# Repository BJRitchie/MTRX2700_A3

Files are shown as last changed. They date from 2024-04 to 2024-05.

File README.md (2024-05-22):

# MTRX2700 Major Project - The a-MAZE-ing Race
## Project Details:
The a-MAZE-ing Race is a competitive maze game with the objective of reaching all the checkpoints on the maze board as fast as possible. 

## Group Members
- Sebastian O'Connell (520443826)
- Ben Ritchie (520479733)
- Luca Agius (520510715)
- Will Ridley-Smith (520466021)

## Roles & Responsibilities
### Will Ridley-Smith
- Joystick Module
- Servo/Joystick integration 
- 3D printing and assembly

### Luca Agius
- LDR, GUI, and Serial Modules
- Documentation lead

### Sebastian O'Connell
- LDR, GUI, and Serial Modules
- Presentation slides
- Minutes documentation

### Ben Ritchie
- CAD design of gimbaling system 
- Servo Module
- Servo/Joystick integration
- Minutes documentation

## Module Breakdown

## Serial Communication Module
### Summary
Serial communication facilitates the transmission of data between modules to ensure they work together correctly.
### Usage
The LDR and GUI modules rely on packets sent over serial to communicate and ultimately carry out a usuable function. Using an interrupt based approach, the modules can function simultaneously, allowing for the game to function smoothly. 
### Valid input
Sorted data can be inputted into the SerialOutputString function and sent over USART1 to the PC to utilise serial communication.
### Functions and modularity
#### Transmission
SerialOutputString: This function is the most essential function in the serial communicaion process. It is used to output a specific string over the serial port using a pre-determined baud rate. The baud rate must match that at the receiving end.
SerialInitialise: Initialises the serial port and specified baud rate
### Testing
Messages can manually be sent over the serial port using the SerialOutputBuffer. To confirm that these messages are being sent/received, a terminal such as the PuTTY terminal can be used. The PuTTY terminal should be given the correct COM line to read from, and the appropriate baud rate. When a message is written into the SerialOutputBuffer and the code is run, the PuTTY terminal should receive the string. 

## Joystick Module
### Summary
Potentiometers track the rotation of a joystick on 2 axis'. A voltage divider is used to track the values of the position of the potentiometer. This voltage signal is passed into an analog to digital converter to get the values. A range is found for the joystick and then the values are mapped so that each coordinate is a value from 0-1000.

### Usage
To use the module, simply initialise the ADC with InitialiseADC() and use get_joystick_values() to get the current coordinates of the joystick. The values of the coordinates range from 0-1000. WHen the joystick is connected, x is 0 when all the way to the left and 1000 when all the way to the right. Y is 1000 when all the way forwards and 0 when all the way back. In this assignment, a loop continuously calls get_joystick_values() so that we are always checking the position of the joystick.

### Valid input
A pointer to a valid struct joystick_coordinates should be passed into the get_joystick_values() function.
Variable voltage should be connected to PA1 and PA5 and should have a max value of 3V.

### Functions and modularity
InitialiseADC() runs all required setup for the ADC module.
get_joystick_values() simply returns the current coordinates of the joystick.
All functionality is encapsulated within these functions.

### Testing
Connect inputs for the joystick module and initialise Serial. Use Serial Output to print the values from ADC to the terminal on a computer. Check that the y value varies when moving the joystick forward and backwards, and the x value varies when moving side to side.

Print the mapped x and y values to the screen and check that at the furthest forward position, y is 1000, and the furthest backwards, y is 0. Also check that all the way to the right, x is 1000 and all the way to the left, x is 0.

## Servo Module
### Summary
The servo module is designed for simple integration, where the user can input a value from 0 to 1, where 0 is the minimum allowable angular displacement and 1 is the maximum allowable position for the servo. Each servo is described inside a struct that contains the responsible hardware timer, channel and the maximum and minimum permissible PWM values. It also contains parameters that relate to velocity control functions. 

The servo module also contains a PID controller for velocity, which uses the PWM signal period to adjust the servo velocity and the on-board gyroscope to check the actual rotational velocity. The target (requested) velocity can be adjusted at any time using the setTargetVelocity function. This value is check at a regular interval by the PID controller, which will adjust the PWM period until it reaches an acceptable error range. 

### Usage
The servo module will be linked to the joystick module. The joystick module will request a value from 0 to 1 in the x and y axes and the servos will go to this position. 

One could also configure the joystick to control the rotational velocity of the board by adjusting the target velocity values, and the velocity control module will adjust the PWM period as required. 

### Valid input
A positional value from 0 to 1 can be requested. 

### Functions and modularity
#### Positional Control 
servoGoToFractionalPosition: will go to the requested fraction of its positional range. 
setServoPWM: sets the requested PWM value. 

#### Velocity Control 
initPIDController: initialises the PID controller for the servo 
setTargetVelocity: sets the target rotational velocity of the servo.
servoGoToFractionalVelocity: make the servo go at a fraction of the allowable range. 

### Testing

## LDR/Gameplay Module 
### Summary
There are 4 LDRs used in the game that are setup to work with the ADC ports. There is one LDR which is used as the starting point of the game, and when this LDR is blocked for three seconds, the game begins. Hardware timers are used to time the game, one timer counts every seconds and another timer counts every 100th of a second. Once the game is being played, the fast-acting timer checks to see whether any of the other three LDRs have been blocked. If all three have been blocked once, then the game is finished.

### Usage
The LDR module features the resistive sensors required for this assignment and it they are used inside the maze. This module is essentially the module where the game is run and the game settings are configured.
The LDRs are powered off of the STM board but they are wired with resistors to ground. A wire connects the LDR output to a comparator which is compared to a tuned potentiometer. The inputs to the ADC ports are taken from the four outputs of the LM324 comparator

### Valid input
Changing light levels incident on the LDR are valid for using this module. The best way to use this is to have a very bright light in contrast with a very dark light.

### Functions and modularity
The ADC ports are used to check the readings from the LDRs and then interpreted using a scale value. This module only has a 2-value scale as it only cares if the LDR is on or off. The scale values are then stored in the ADC port which can be used in the main function. 
The timer code is taken from the previous assignment but has a struct to initialise the timers and some other functions to configure the timers
The gameplay code is a separate file and contains functions relating to how the game is played. This includes functions that call the ADC, interrupt, and timer initialisation functions from the other modular files. This part of the code has a struct called GameData which contains the game setting information and configuration, this can be changed to change the game settings slightly. It also contains a function called FlashEndLights which is called once all the LDRs/checkpoints have been passed and this flashes until the game is reset.

### Testing
To test this module, the STM LEDs have been configured to visually debug the system. The LDRs are set to trigger 1 of 2 LEDs, an LED for off and an LED for on. If the LED changes when you block the LDR then the potentiometer, LDR, and code has been tuned effectively. 
The LEDs are then also used to test whether the gameplay is working smoothly. During phase 1, the LEDs are set to only respond to the starting point LDR and will change when that LDR is blocked. Between game phase 1 and 2, three LEDs flash to inform the user that the game is about to begin. Then in the game playing phase, 2 LEDs are then set to respond to 1 LDR as describe earlier. Since there are 3 LDRs used in this phase, then 6 LEDs are used. When each LDR has been blocked once, you know the game is finished because the cool end light patterns will flash. To reset the game, hit the blue button and you will see all the LEDs flash and then the game will reset to phase 1. 

## GUI Module 
maze
### Summary
The GUI is generated using python code to display a timer when the game starts, and employs a leaderboard to track the quickest times. 
### Usage
The GUI module aims to replicate the quality features of a real arcade game. This module is essential in transforming the design from a casual toy into a competitive game with various interactive and engaging features. Implementing a timer with an associated leaderboard, music and checkpoint indicators changes the games usage to being a quantifiable race.  
### Valid input
The GUI code must be run on a valid python coding platform that has the capability to generate a GUI pop-up application (such as VSCode).
### Functions and modularity
The timer will be idle until it receives a specific packet over serial indicating the game has started - this occurs when the maze marble sits in the starting position for three seconds. The timer will continue to run until all of the checkpoints are reached. Once all the checkpoints are reached by the marble, a packet will be sent over serial indicating the game has ended. The timer will stop, reset to zero and sit idle until the game is started again. Additionally, once the game ends, there is a pop-up request for a username input. After inputting a username, the time taken to finish the game and username will be displayed on the leaderboard in the appropriate position, with the fastest time at the top of the leaderboard.
#### Serial
The python module "pyserial" is installed onto the device and imported into the code to access serial. The serial packet is sent from the STM32F3Discovery board and interpretted by the python code.
#### tkinter
The python module "tkinter" is installed onto the device and imported into the code to generate the GUI. Within the GUI, there is a leaderboard, timer display, and username input request. 
#### Timer 
The python module "time" is imported to run the count.
#### Soundtrack
The python module "pygame" is installed onto the device and imported into the code to play music.

### Testing
- When inputting a name, the word length cannot exceed 20 characters. If it does exceed 20 characters, a warning message is displayed which requests a shorter username.
- A manual message can be sent over serial from the STM32F3Discovery board using the SerialOutputString function instead of using the LDR module to test the functionality of the checkpoints, soundtrack and sound effects, post-game username request and leaderboard. This is useful for when the LDR module is not available for use.
- If the game length exceeds the length of the music, the music will repeat to maintain game immersion
- To ensure clarity, once a checkpoint has been reached, it cannot be triggered again during the game instance. This means the sound effect will not be re-played in the circumstance where the marble moves past the checkpoint again.

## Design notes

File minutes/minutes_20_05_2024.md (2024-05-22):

## Date - 01/05/2024

### Present: 
- Luca
- Ben
- Seb
- Will

### Meeting Purpose
- integrate the modules 

### Previous Actions 
- worked on modules and tested their operation 

### Current Items
- integrate servo and joystick modules
    - put together into board 
- integrate the LDR and gyro modules 

### New Items
Luca: commenting and readme  
Seb: commenting and readme
Ben: commenting and readme
Will: final assembly of board and test operation   

### Next Meeting Date 
Wednesday, 22nd of May

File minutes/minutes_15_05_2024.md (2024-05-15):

## Date - 15/05/2024

### Present: 
- Luca
- Ben
- Seb
- Will

### Meeting Purpose
- Continue to work on project modules

### Previous Actions 
- Continue to work on project modules

### Current Items
- Work on integration of modules in main
- Use LDR data to start and stop the python gui timer
- Configure the motors
- Print the maze

### New Items
Luca & Seb: Integrate the serial, LDR and python gun timer 
Ben: Continue work on designing the gimbaling system and driving servos
Will: Continue work on joystick and gyro module and getting input from potentiometers

### Next Meeting Date 
Monday, 20th of May

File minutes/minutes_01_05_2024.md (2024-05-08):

## Date - 01/05/2024

### Present: 
- Luca
- Ben
- Seb
- Will

### Meeting Purpose
- Continue to work on project modules

### Previous Actions 
- Discuss the separate modules and functionality

### Current Items
- Work on maze design
- Work on maze frame
- Work on LDR detection and communication with micro-controller

### New Items
Luca: Work on LDR reading module 
Seb: work on Serial -> Python GUI  
Ben: work on designing the gimbaling system 
Will: work on joystick/ control system  

### Next Meeting Date 
Wednesday, 8th of May

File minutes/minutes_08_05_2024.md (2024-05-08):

## Date - 08/05/2024

### Present: 
- Luca
- Ben
- Seb
- Will

### Meeting Purpose
- Continue to work on project modules
- Define added module utilising gyro and accelerometer for Will to work on

### Previous Actions 
- Continue work on project modules

### Current Items
- Work on gimballing maze frame
- Use 2 STM32's to drive 4 servos, 2 each. Minimising current and voltage draw.
- Utilise magnets to switch out maze designs
- Work on joystick
- Use RP7510 for potentiometers
- Add STM32 with gyro and accelerometer on the maze to track 
  position and acceleration
- Work on LDR detection and communication with micro-controller

### New Items
Luca: Work on LDR reading module 
Seb: work on Serial -> Python GUI  
Ben: work on designing the gimbaling system and driving servos
Will: work on joystick and gyro module and getting input from potentiometers

### Next Meeting Date 
Wednesday, 15th of May

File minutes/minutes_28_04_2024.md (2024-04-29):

## Date - 28/04/2024

### Present: 
- Luca
- Ben
- Seb 

### Meeting Purpose
- Discuss previously developed ideas
- Discuss modules and determine work to complete before next lab 

### Previous Actions 
- Ben and Luca generated a number of ideas and settled on the Maze Game 

### Current Items
- Discussed gimbaling systems
    - solenoid-based 
    - 2 servos 
    - roller system: 2 servos turn tires against a sphere which is connected to the plane 
    - ways to detach the servos from the maze itself 
- Discussed board design 
    - LEGO was determined as ideal for prototyping
    - final product will be 3D printed 
    - Will mentioned some ideas of swapping out mazes 
- Assigned tasks 

### New Items
Luca: Work on LDR reading module 
Seb: work on Serial -> Python GUI  
Ben: work on designing the gimbaling system 
Will: work on joystick/ control system  

### Next Meeting Date 
Wednesday the 1st of May

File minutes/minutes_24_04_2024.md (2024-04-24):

## Date - 24/04/2024

### Present: 
- Ben
- Sebastian
- Will 
- Luca

### Meeting Purpose
- decide on project concept 

### Previous Actions 
NA

### Current Items
#### Assignment Requirements
- An actuator 
- A resistive sensor
- Some interaction with the computer 

#### Available to Us:
- PTU
- Lidar
- discovery board sensors
- capacitive touch sensors
- flexible potentiometer 
- 

#### Car Game: 
- have something fall through the serial 

#### Wall of Boxes: 
- people sitting on wall of boxes 
- choose a random card, has punishment
- sometimes will break the wall

Comments: 
- difficult to implement 
- doesn't use many sensors 

#### What we want in the game: 
- Some kind of GUI or game shown on the screen 
- Will can make a joy-stick
    - ticks the actuator box 

#### Pictionary Idea: 
- Use joy stick to draw an image
- Could use a 3D printer setup to physically draw it
- Or a display on the computer 

#### Maze Idea
- Approved by tutor
- Use a joystick (that operates using potentiometers) to tilt a maze that contains a marble. 
- Maze platform is tilted using servos 
    - use this system with servos: https://youtu.be/JkJ851Pya0I?si=VTKCS693HPFE_Ybs&t=647 
- Marble has to hit a certain number of checkpoints to win the game 
    - checkpoints are LDRs
- Score/progress and count down is displayed on the computer 
- Can make the checkpoints moveable 

### New Items

### Next Meeting Date 
Soon, before the next lab but exact date is TBD

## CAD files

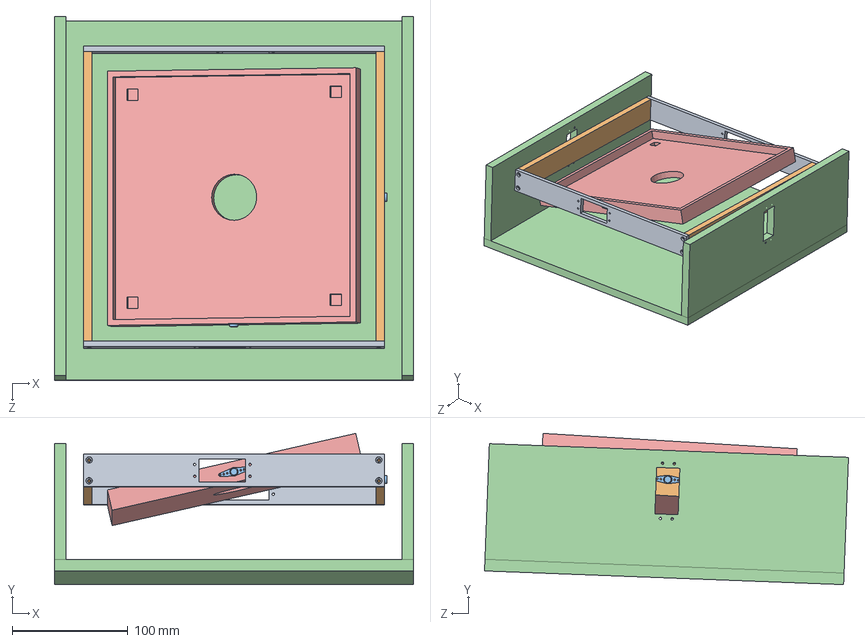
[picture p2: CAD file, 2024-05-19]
gimbal_design/gimbal_assem.SLDASM
310.4 x 130.6 x 314.4 mm
board_connector
ground_connection
mock_horn2 x 2
horn_connection x 2
servo_connection x 2

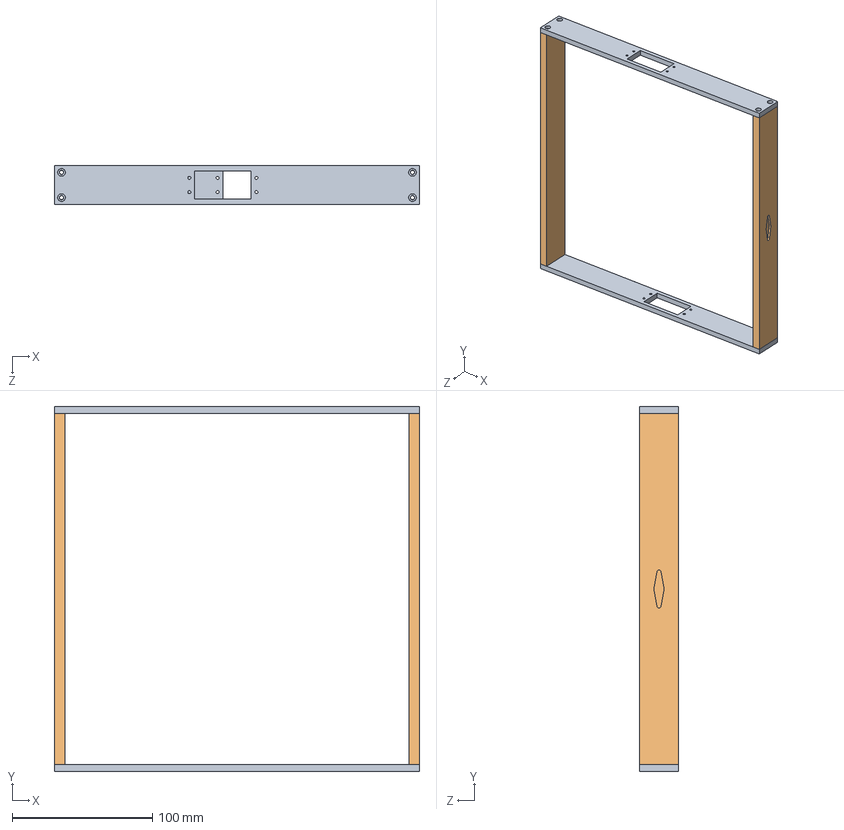
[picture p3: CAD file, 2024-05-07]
gimbal_design/rotator_assem.SLDASM
260.2 x 260.2 x 28.0 mm
horn_connection x 2
servo_connection x 2

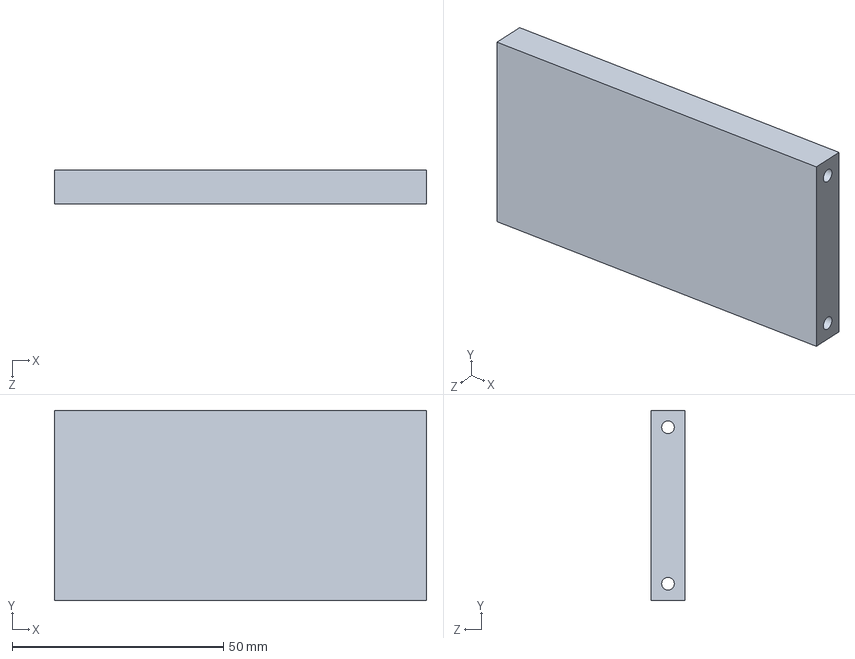
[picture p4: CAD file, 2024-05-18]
Joystick CAD Model/Main Base Side.SLDPRT
88.0 x 45.0 x 8.00 mm

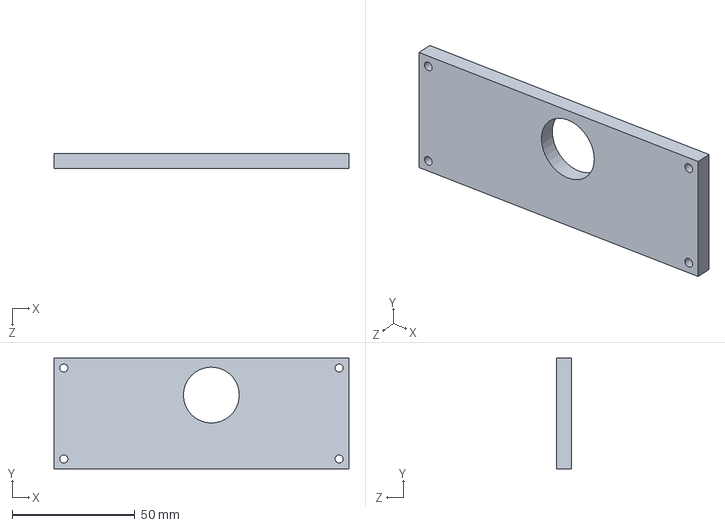
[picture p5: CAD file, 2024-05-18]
Joystick CAD Model/Main Base Bearing Side Other.SLDPRT
120.0 x 45.0 x 6.00 mm

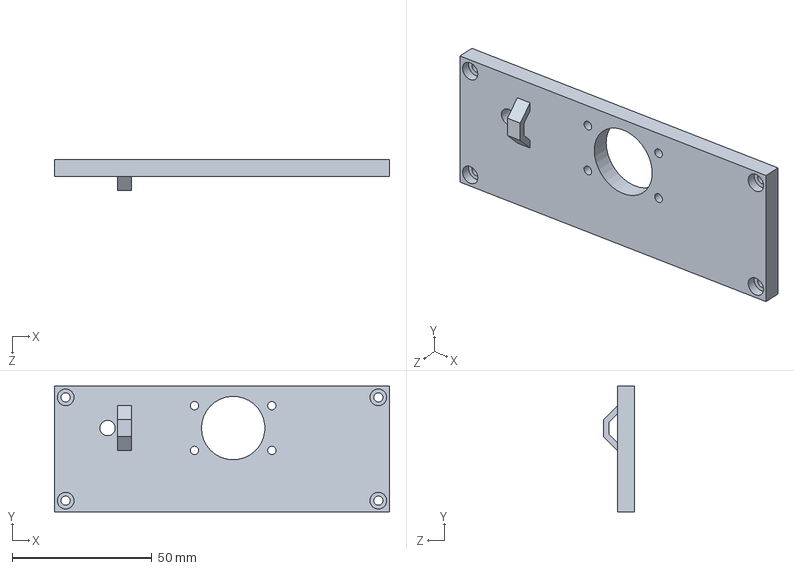
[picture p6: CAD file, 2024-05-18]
Joystick CAD Model/Main Base Bearing Side.SLDPRT
120.0 x 45.0 x 11.0 mm

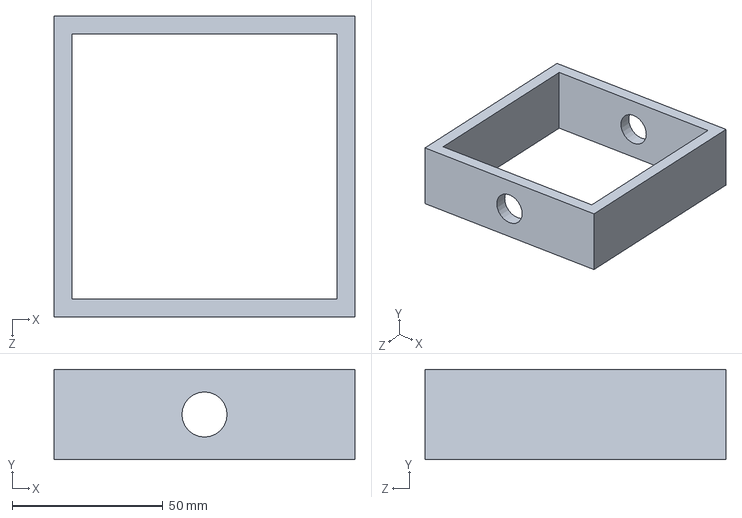
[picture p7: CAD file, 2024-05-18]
Joystick CAD Model/Main Base.SLDPRT
100.0 x 30.0 x 100.0 mm

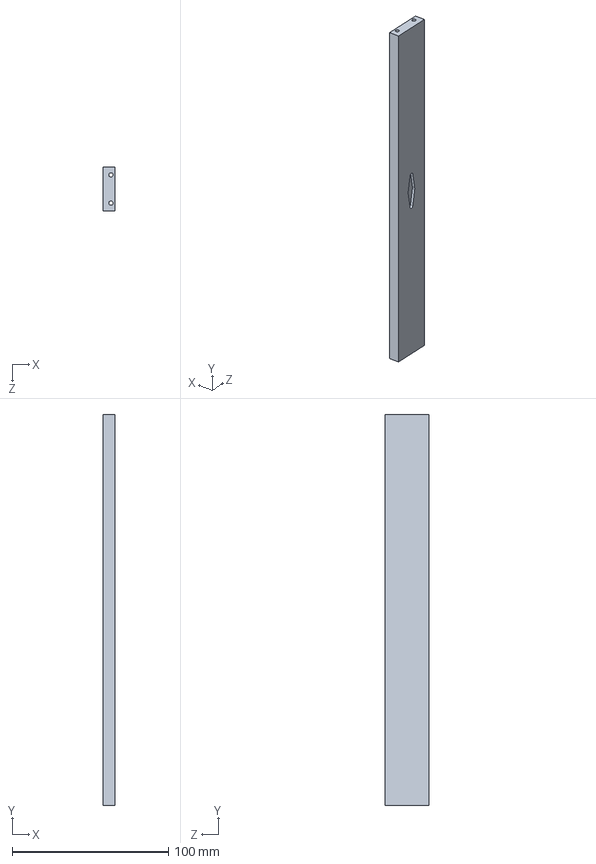
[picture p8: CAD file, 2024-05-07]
gimbal_design/rotator/horn_connection.SLDPRT
7.50 x 250.2 x 28.0 mm

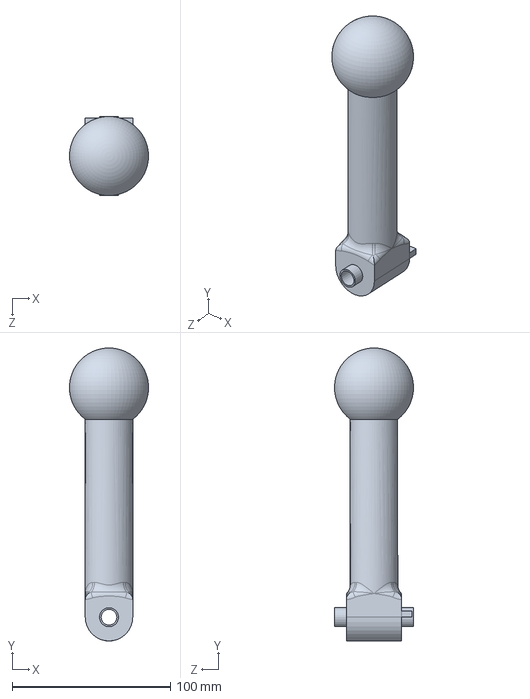
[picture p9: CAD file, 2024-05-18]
Joystick CAD Model/Handle.SLDPRT
49.9 x 185.0 x 49.9 mm

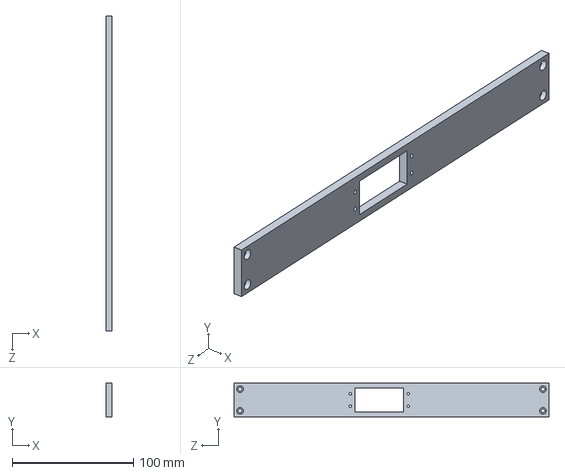
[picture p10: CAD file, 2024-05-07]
gimbal_design/rotator/servo_connection.SLDPRT
5.00 x 28.0 x 260.2 mm

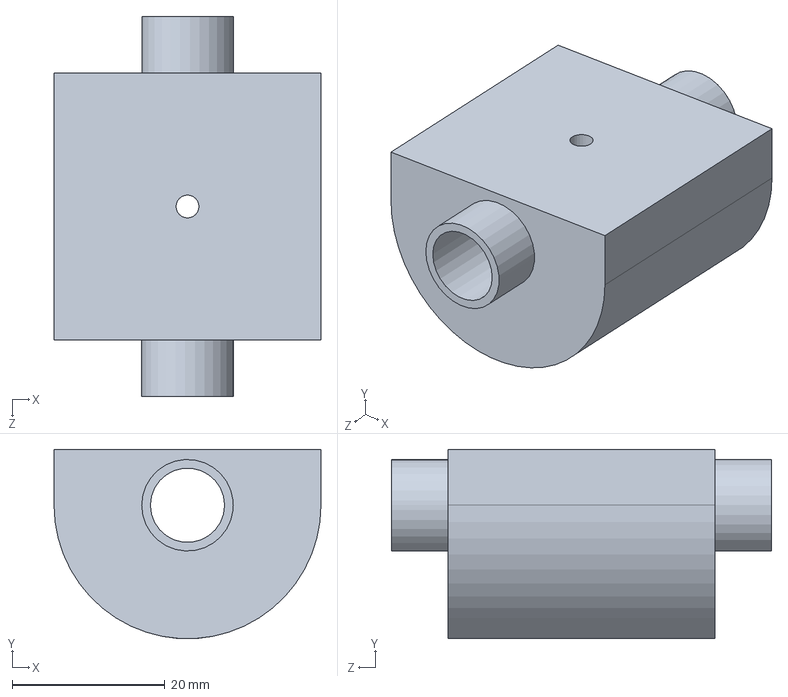
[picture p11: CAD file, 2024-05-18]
Joystick CAD Model/Handle Quick Print.SLDPRT
35.0 x 24.8 x 49.9 mm

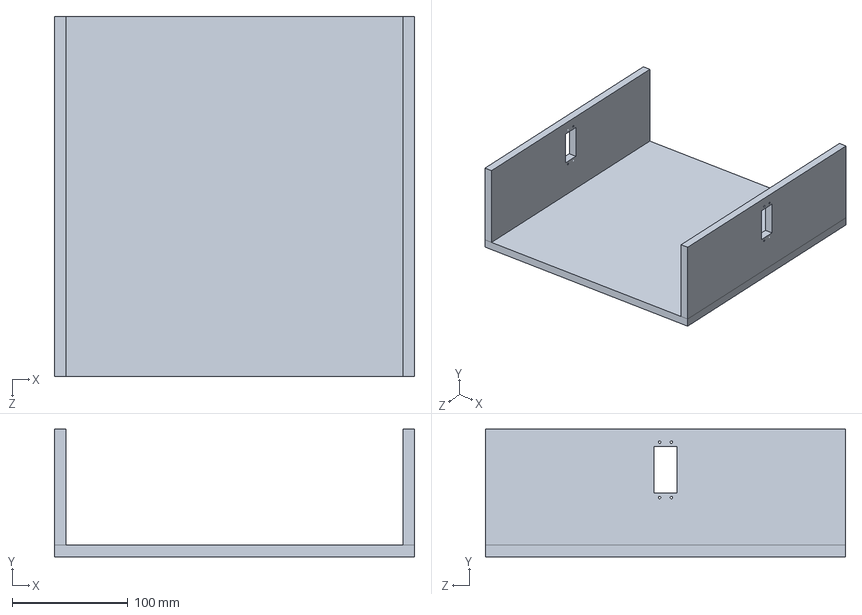
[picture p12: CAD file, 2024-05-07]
gimbal_design/ground_connection.SLDPRT
310.4 x 110.0 x 310.4 mm

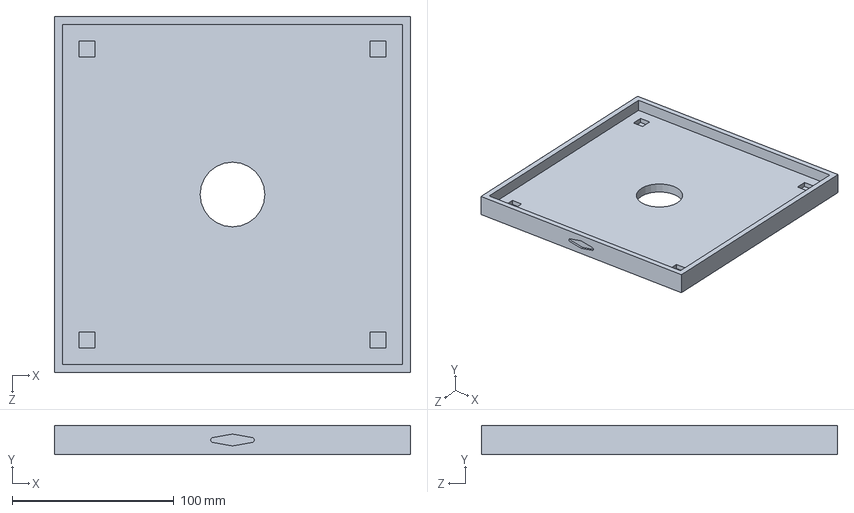
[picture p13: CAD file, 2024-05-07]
gimbal_design/board_connector.SLDPRT
220.0 x 18.0 x 220.0 mm

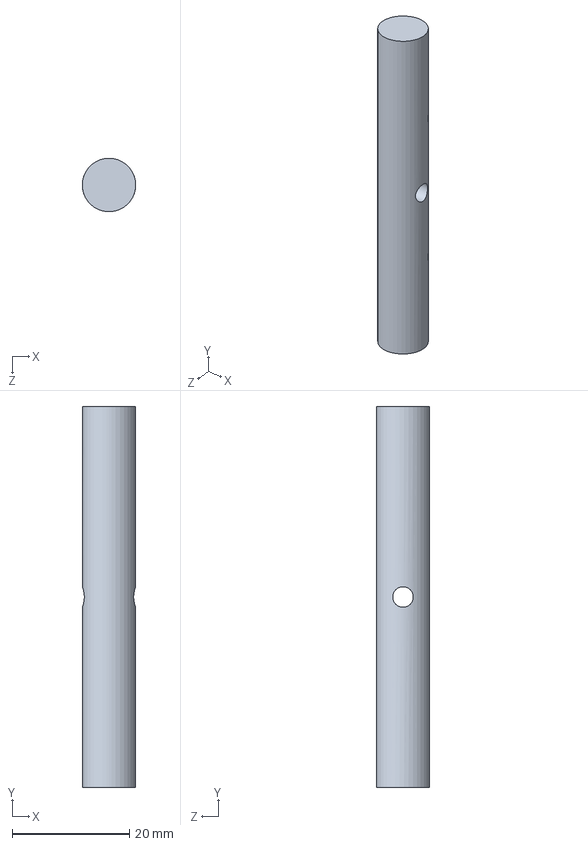
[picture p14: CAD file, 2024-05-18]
Joystick CAD Model/Axle.SLDPRT
9.12 x 65.0 x 9.12 mm

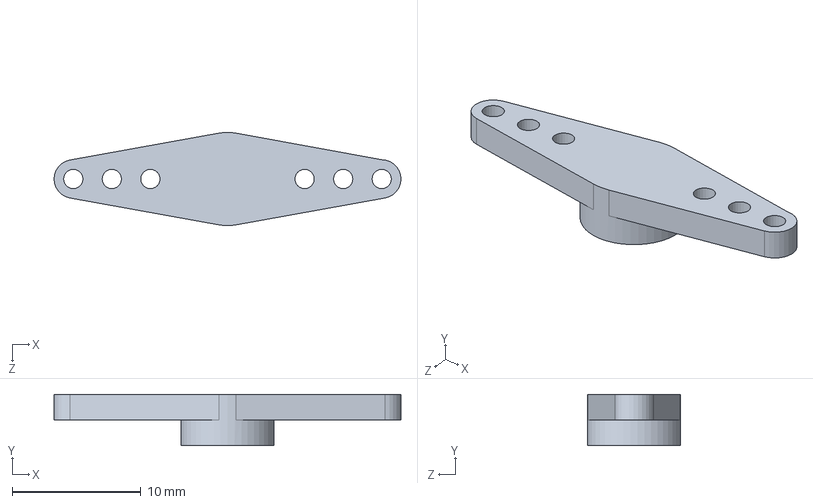
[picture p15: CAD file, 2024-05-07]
gimbal_design/mock_horn2.SLDPRT
27.0 x 4.00 x 7.26 mm

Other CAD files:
Joystick CAD Model/Joystick.SLDASM
gimbal_design/HS-322HD-Servo.SLDASM
gimbal_design/x_rotation.SLDPRT
gimbal_design/mock_horn.SLDPRT
Joystick CAD Model/Bearing.SLDPRT
Joystick CAD Model/Handle Quick Print 2.SLDPRT
Joystick CAD Model/Inner Base.SLDPRT
Joystick CAD Model/Potentiometer Standoff.SLDPRT
Joystick CAD Model/Potentiometer.SLDPRT
Joystick CAD Model/Socket Head M3x20.SLDPRT
gimbal_design/HS-322HD-1642818504.SLDASM
gimbal_design/HS-322HD-1642818504.stp

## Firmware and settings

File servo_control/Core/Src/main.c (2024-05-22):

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
/* Includes ------------------------------------------------------------------*/
#include "main.h"

/* USER CODE BEGIN Includes */
#include "servo.h"
#include "timer.h"

/* USER CODE END Includes */

I2C_HandleTypeDef hi2c1;

SPI_HandleTypeDef hspi1;

TIM_HandleTypeDef htim2;
TIM_HandleTypeDef htim3;

USART_HandleTypeDef husart1;

PCD_HandleTypeDef hpcd_USB_FS;

void SystemClock_Config(void);
static void MX_GPIO_Init(void);
static void MX_I2C1_Init(void);
static void MX_SPI1_Init(void);
static void MX_USB_PCD_Init(void);
static void MX_TIM2_Init(void);
static void MX_USART1_Init(void);
static void MX_TIM3_Init(void);
/**
  * @brief  The application entry point.
  * @retval int
  */
int main(void)
{

  /* MCU Configuration--------------------------------------------------------*/

  /* Reset of all peripherals, Initializes the Flash interface and the Systick. */
  HAL_Init();

  /* Configure the system clock */
  SystemClock_Config();

  /* Initialize all configured peripherals */
  MX_GPIO_Init();
  MX_I2C1_Init();
  MX_SPI1_Init();
  MX_USB_PCD_Init();
  MX_TIM2_Init();
  MX_USART1_Init();
  MX_TIM3_Init();
  /* USER CODE BEGIN 2 */

  // start the timers
  HAL_TIM_PWM_Start(&htim2, TIM_CHANNEL_1);
  HAL_TIM_PWM_Start(&htim2, TIM_CHANNEL_2);
  HAL_TIM_PWM_Start(&htim3, TIM_CHANNEL_1);
  HAL_TIM_PWM_Start(&htim3, TIM_CHANNEL_2);
//  HAL_TIM_PWM_Start(&htim2, TIM_CHANNEL_3);
//  HAL_TIM_PWM_Start(&htim2, TIM_CHANNEL_4);

  // initialise the PID controller 
//  initPIDController(&Servo1, &PIDVelocityController1);

  /* USER CODE END 2 */

  /* Infinite loop */
  /* USER CODE BEGIN WHILE */


  while (1)
  {
	  if ((GPIOA->IDR & 0x01) == 1) {
//
//		  setTargetVelocity(&Servo1, 1000);
//
		  servoGoToFractionalPosition(&Servo1, 0);
		  servoGoToFractionalPosition(&Servo2, 1-0);
		  servoGoToFractionalPosition(&Servo3, 0);
		  servoGoToFractionalPosition(&Servo4, 1-0);

//		  // wait until button is released
		  while ((GPIOA->IDR & 0x01)) {};
	  }
	  else {
//
		  servoGoToFractionalPosition(&Servo1, 1);
		  servoGoToFractionalPosition(&Servo2, 1-1);
		  servoGoToFractionalPosition(&Servo3, 1);
		  servoGoToFractionalPosition(&Servo4, 1-1);

//		  setTargetVelocity(&Servo1, -1);
	  }


    /* USER CODE END WHILE */

    /* USER CODE BEGIN 3 */
  }
  /* USER CODE END 3 */
}

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


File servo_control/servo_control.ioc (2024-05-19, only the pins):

Mcu.UserName=STM32F303VCTx
PA0.GPIO_Label=B1 [Blue PushButton]
PA0.Signal=GPIO_Input
PA1.Signal=S_TIM2_CH2
PA10.Signal=USART1_RX
PA11.GPIO_Label=DM
PA11.Signal=USB_DM
PA12.GPIO_Label=DP
PA12.Signal=USB_DP
PA13.GPIO_Label=SWDIO
PA13.Signal=SYS_JTMS-SWDIO
PA14.GPIO_Label=SWCLK
PA14.Signal=SYS_JTCK-SWCLK
PA15.Signal=S_TIM2_CH1_ETR
PA2.Signal=S_TIM2_CH3
PA3.Signal=S_TIM2_CH4
PA4.Signal=S_TIM3_CH2
PA5.GPIO_Label=SPI1_SCK [L3GD20_SCL/SPC]
PA5.Signal=SPI1_SCK
PA6.GPIO_Label=SPI1_MISO [L3GD20_SA0/SDO]
PA6.Signal=SPI1_MISO
PA7.GPIO_Label=SPI1_MISO [L3GD20_SDA/SDI/SDO]
PA7.Signal=SPI1_MOSI
PA8.Signal=USART1_CK
PA9.Signal=USART1_TX
PB3.GPIO_Label=SWO
PB3.Signal=SYS_JTDO-TRACESWO
PB6.GPIO_Label=I2C1_SCL [LSM303DLHC_SCL]
PB6.Signal=I2C1_SCL
PB7.GPIO_Label=I2C1_SDA [LSM303DLHC_SDA]
PB7.Signal=I2C1_SDA
PC14-OSC32_IN.GPIO_Label=OSC32_IN
PC14-OSC32_IN.Signal=RCC_OSC32_IN
PC15-OSC32_OUT.GPIO_Label=OSC32_OUT
PC15-OSC32_OUT.Signal=RCC_OSC32_OUT
PC6.Signal=S_TIM3_CH1
PE0.GPIO_Label=MEMS_INT1 [L3GD20_INT1]
PE0.Signal=GPXTI0
PE1.GPIO_Label=MEMS_INT2 [L3GD20_DRDY/INT2]
PE1.Signal=GPXTI1
PE10.GPIO_Label=LD5 [Orange Led]
PE10.Signal=GPIO_Output
PE11.GPIO_Label=LD7 [Green Led]
PE11.Signal=GPIO_Output
PE12.GPIO_Label=LD9 [Blue Led]
PE12.Signal=GPIO_Output
PE13.GPIO_Label=LD10 [Red Led]
PE13.Signal=GPIO_Output
PE14.GPIO_Label=LD8 [Orange Led]
PE14.Signal=GPIO_Output
PE15.GPIO_Label=LD6 [Green Led]
PE15.Signal=GPIO_Output
PE2.GPIO_Label=DRDY [LSM303DLHC_DRDY]
PE2.Signal=GPXTI2
PE3.GPIO_Label=CS_I2C/SPI [L3GD20_CS_I2C/SPI]
PE3.Signal=GPIO_Output
PE4.GPIO_Label=MEMS_INT3 [LSM303DLHC_INT1]
PE4.Signal=GPXTI4
PE5.GPIO_Label=MEMS_INT4 [LSM303DLHC_INT2]
PE5.Signal=GPXTI5
PE8.GPIO_Label=LD4 [Blue Led]
PE8.Signal=GPIO_Output
PE9.GPIO_Label=LD3 [Red Led]
PE9.Signal=GPIO_Output
PF0-OSC_IN.GPIO_Label=OSC_IN
PF0-OSC_IN.Signal=RCC_OSC_IN
PF1-OSC_OUT.GPIO_Label=OSC_OUT
PF1-OSC_OUT.Signal=RCC_OSC_OUT

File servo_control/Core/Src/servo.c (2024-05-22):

#include "servo.h"
#include "timer.h"
#include "stm32f303xc.h"


#define CLOCK_FREQ 48000000
#define X_AXIS 0
#define Y_AXIS 1
#define Z_AXIS 2

struct _Servo {
	// servo variables
	TIM_TypeDef* TIMx;	// timer to be used
	uint8_t channel;    // PWM channel
	float position[3];  // positions determined by the gyro
	float velocity;  // velocity determined by the gyro
	float target; 	// target position
	float target_velocity; // target velocity
	uint32_t max_pwm; 	// the max pwm the servo will allow
	uint32_t min_pwm; 	// the min pwm the servo will take
	uint32_t max_arr; 	// the max ARR value allowed
	uint32_t min_arr; 	// the min ARR value allowed

	// Controller Variables 
	HardwareTimer* TIMx_init;   // initialisation params for timer to be used for PID controller
	uint32_t loop_time; 		// time between controller updates
	float Kp; 				// servo controller gain
	float Td; 				// controller derivative time constant
	float Ti; 				// controller integral time constant
	float error_sum; 		// integral error sum 
	float error_last; 		// the previous error  
	void (*PIDController)(); 	// the controller code block to be used for this servo 
};

Servo Servo1 = {
	.TIMx = TIM2,
	.channel = 1,
	.position = {0,0,0},
	.velocity = 0,
	.target = 0,
	.target_velocity = 0,
	.max_pwm = 2500,
	.min_pwm = 700,
	.max_arr = 80000,
	.min_arr = 3000,

	// pid variables
	.TIMx_init = &TIM4_init,
	.loop_time = 10000,
	.Kp = 10,
	.Td = 0,
	.Ti = 1000,
	.error_sum = 0,
	.PIDController = 0x00
};

Servo Servo2 = {
	.TIMx = TIM2,
	.channel = 2,
//	.position = {0,0,0},
//	.velocity = 0,
//	.target = 0,
//	.target_velocity = 0,
	.max_pwm = 2500,
	.min_pwm = 700,
//
//	.TIMx_init = &TIM4_init,
//	.loop_time = 100000,
//	.Kp = 1,
//	.Td = 0,
//	.Ti = 1000,
//	.error_sum = 0,
//	.PIDController = 0x00
};

Servo Servo3 = {
	.TIMx = TIM3,
	.channel = 1,
//	.position = {0,0,0},
//	.velocity = 0,
//	.target = 0,
//	.target_velocity = 0,
	.max_pwm = 2500,
	.min_pwm = 700,
//
//	.TIMx_init = &TIM4_init,
//	.loop_time = 100000,
//	.Kp = 1,
//	.Td = 0,
//	.Ti = 1000,
//	.error_sum = 0,
//	.PIDController = 0x00
};

Servo Servo4 = {
	.TIMx = TIM3,
	.channel = 2,
//	.position = {0,0,0},
//	.velocity = 0,
//	.target = 0,
//	.target_velocity = 0,
	.max_pwm = 2500,
	.min_pwm = 700,
//
//	.TIMx_init = &TIM4_init,
//	.loop_time = 100000,
//	.Kp = 1,
//	.Td = 0,
//	.Ti = 1000,
//	.error_sum = 0,
//	.PIDController = 0x00
};


// a function to make servo move to a point in its range of motion
// Inputs:
// - Servo*: address of the servo struct being used
// - frac: the fraction of the servos range to go to (0 to 1)
void servoGoToFractionalPosition(Servo *servo, float frac) {
	uint32_t max = servo->max_pwm;
	uint32_t min = servo->min_pwm;
	double range = max - min;

	// map to pwm range
	uint32_t pwm = min + range*frac;

	// set the pwm val
	setServoPWM(servo, pwm);
}

void setServoPWM(Servo *servo, uint32_t pwm){

	if (servo->channel == 1) {
		servo->TIMx->CCR1 = pwm;
	}
	else if (servo->channel == 2) {
		servo->TIMx->CCR2 = pwm;
	}
	else if (servo->channel == 3) {
		servo->TIMx->CCR3 = pwm;
	}
	else if (servo->channel == 4) {
		servo->TIMx->CCR4 = pwm;
	}
}

void servoGoToFractionalVelocity(Servo *servo, float frac) {
	// check fractional input 
	if (frac < 0) {
		frac = 0.; 
	}
	else if (frac > 1) {
		frac = 1.; 
	}
	
	uint32_t max_arr = servo->max_arr; 
	uint32_t min_arr = servo->min_arr; 
	float slope = (float)max_arr - (float)min_arr;

	// map to arr range
	uint32_t arr = min + slope*frac;

	// check the counter 
	if (servo->TIMx->CNT > arr) {
		TIM2->CNT = 0; // reset counter
	}
	servo->TIMx->ARR = arr; // set the arr value 
}



// generate an output string describing the servo
void servoString(Servo* servo, uint8_t* str) {
	sprintf(str, "channel: %d, target_velocity: %0.3f, velocity: %0.3f",
			servo->channel, servo->target_velocity, servo->velocity);
}

float average(float arr[], uint32_t size) {
	float sum = 0;

	for (uint32_t i=0; i < size; i++ ) {
		sum += arr[i];
	}
	return (float)(sum/size);
}

void shift_array(float arr[], uint32_t size, float new_arr[], float new_value) {
	// shift up one and insert new value 
	new_arr[0] = new_value;

    for (size_t i = 1; i < (size); i++) {
        new_arr[i] = arr[i - 1];
    }
}

void setPIDController(Servo *servo, void (*PIDControllerFunction)()) {
	servo->PIDController = PIDControllerFunction; 	// set pid controller func in servo struct 
	setCompletionFunc(servo->TIMx_init, PIDControllerFunction); // set as timer completion func 
}

void initPIDController(Servo *servo, void (*PIDControllerFunction)()) {
	enable_timer_interrupt(); // enable the interrupts 
	BSP_GYRO_Init(); // enable gyro

	// set the controller function 
	setPIDController(servo, PIDControllerFunction);

	servo->PIDController = PIDControllerFunction;
	setCompletionFunc(servo->TIMx_init, PIDControllerFunction);

	// initialise a timer to call repeated checks
	// PID is the callback function
	TimerInitialise(servo->TIMx_init, servo->PIDController);

	// set the period between checks
	setPrescaleValue(servo->TIMx_init, 47);
	setARRValue(servo->TIMx_init, servo->loop_time);
}

void setServoTarget(Servo *servo, uint32_t target){
	servo->target = target; 
}

void setTargetVelocity(Servo *servo, float target_vel){
	servo->target_velocity = target_vel;
}



float pid_velocity_controller_inner(Servo* servo) {
	// unpack PID variables
	float Kp = servo->Kp;
	float Ti = servo->Ti;
	float Td = servo->Td;
	float error_sum = servo->error_sum;
	float error_last = servo->error_last;

	float error = servo->target_velocity - servo->velocity;
	error_sum += error;

	// calc PID components
	float P = error;
	float I = (1/Ti) * error_sum;
	float D = Td * (error - error_last);

	// apply PID equation 
	float arr_frac = Kp * (P + I + D); 

	// update PID values
	servo->error_last = error;
	servo->error_sum = error_sum;

	return arr_frac;
}

void update_position_values(Servo* servo, uint32_t axis) {
	float gyro_values[3];
	float new_arr[3];

	// get the current gyro values
	BSP_GYRO_GetXYZ(&gyro_values[0]);
	float new_value = gyro_values[axis]/20000;

	// shift in the new value
	float* old_arr = servo->position;
	shift_array(old_arr, 3, new_arr, new_value);

	servo->position[0] = new_arr[0];
	servo->position[1] = new_arr[1];
	servo->position[2] = new_arr[2];

}
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

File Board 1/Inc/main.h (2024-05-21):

#ifndef __MAIN_H
#define __MAIN_H

#ifdef __cplusplus
extern "C" {
#endif

#include "stm32f3xx_hal.h"

void Error_Handler(void);

#define DRDY_Pin GPIO_PIN_2
#define DRDY_GPIO_Port GPIOE
#define CS_I2C_SPI_Pin GPIO_PIN_3
#define CS_I2C_SPI_GPIO_Port GPIOE
#define MEMS_INT3_Pin GPIO_PIN_4
#define MEMS_INT3_GPIO_Port GPIOE
#define MEMS_INT4_Pin GPIO_PIN_5
#define MEMS_INT4_GPIO_Port GPIOE
#define OSC32_IN_Pin GPIO_PIN_14
#define OSC32_IN_GPIO_Port GPIOC
#define OSC32_OUT_Pin GPIO_PIN_15
#define OSC32_OUT_GPIO_Port GPIOC
#define OSC_IN_Pin GPIO_PIN_0
#define OSC_IN_GPIO_Port GPIOF
#define OSC_OUT_Pin GPIO_PIN_1
#define OSC_OUT_GPIO_Port GPIOF
#define B1_Pin GPIO_PIN_0
#define B1_GPIO_Port GPIOA
#define SPI1_SCK_Pin GPIO_PIN_5
#define SPI1_SCK_GPIO_Port GPIOA
#define SPI1_MISO_Pin GPIO_PIN_6
#define SPI1_MISO_GPIO_Port GPIOA
#define SPI1_MISOA7_Pin GPIO_PIN_7
#define SPI1_MISOA7_GPIO_Port GPIOA
#define LD4_Pin GPIO_PIN_8
#define LD4_GPIO_Port GPIOE
#define LD3_Pin GPIO_PIN_9
#define LD3_GPIO_Port GPIOE
#define LD5_Pin GPIO_PIN_10
#define LD5_GPIO_Port GPIOE
#define LD7_Pin GPIO_PIN_11
#define LD7_GPIO_Port GPIOE
#define LD9_Pin GPIO_PIN_12
#define LD9_GPIO_Port GPIOE
#define LD10_Pin GPIO_PIN_13
#define LD10_GPIO_Port GPIOE
#define LD8_Pin GPIO_PIN_14
#define LD8_GPIO_Port GPIOE
#define LD6_Pin GPIO_PIN_15
#define LD6_GPIO_Port GPIOE
#define DM_Pin GPIO_PIN_11
#define DM_GPIO_Port GPIOA
#define DP_Pin GPIO_PIN_12
#define DP_GPIO_Port GPIOA
#define SWDIO_Pin GPIO_PIN_13
#define SWDIO_GPIO_Port GPIOA
#define SWCLK_Pin GPIO_PIN_14
#define SWCLK_GPIO_Port GPIOA
#define SWO_Pin GPIO_PIN_3
#define SWO_GPIO_Port GPIOB
#define I2C1_SCL_Pin GPIO_PIN_6
#define I2C1_SCL_GPIO_Port GPIOB
#define I2C1_SDA_Pin GPIO_PIN_7
#define I2C1_SDA_GPIO_Port GPIOB
#define MEMS_INT1_Pin GPIO_PIN_0
#define MEMS_INT1_GPIO_Port GPIOE
#define MEMS_INT2_Pin GPIO_PIN_1
#define MEMS_INT2_GPIO_Port GPIOE

#ifdef __cplusplus
}
#endif

#endif

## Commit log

2024-05-04 added files for the gimbal design
    [HS-322HD-1642818504.stp, HS-322HD-Servo.SLDASM, board_connector.SLDPRT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]
2024-05-07 updated the gimbal design
    [board_connector.SLDPRT, gimbal_assem.SLDASM, ground_connection.SLDPRT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]
2024-05-07 updated the design
    [HS-322HD-1642818504.SLDASM, board_connector.SLDPRT, gimbal_assem.SLDASM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]
2024-05-18 Add joystick CAD model
    [Axle.SLDPRT, Bearing.SLDPRT, Handle Quick Print 2.SLDPRT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]
2024-05-19 servo module and integration with joystick
    [gimbal_assem.SLDASM]
2024-05-20 Working multi ADC reading servo driving
2024-05-20 updates servos, pid controllers and configured the serial_to_python module working on my own laptop
2024-05-21 Create Board 1
2024-05-21 Board 1 code uploaded
2024-05-21 Board 1 python submitted
2024-05-21 Board 1 python code submission
2024-05-21 Fix ranges for servos and joystick
    [adc.c, servo.c]
2024-05-21 Update servo module in README.md
2024-05-21 cleaned up the servo module

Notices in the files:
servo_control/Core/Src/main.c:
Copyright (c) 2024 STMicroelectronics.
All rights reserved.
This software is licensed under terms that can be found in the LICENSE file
